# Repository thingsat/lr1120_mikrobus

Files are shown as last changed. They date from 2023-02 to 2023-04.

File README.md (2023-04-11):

# Semtech LR1120 Mikrobus Board

''The [LR1120](https://fr.semtech.com/products/wireless-rf/lora-edge/lr1120) is an ultra-low power device targeting global geolocation applications. It provides multi band LoRa® and Long Range - Frequency Hopping Spread Spectrum (LR-FHSS) communication over sub-GHz and 2.4GHz Industrial, Scientific and Medical (ISM) bands as well as licensed S-Band for satellites. It integrates a Cloud-native multi-constellation global navigation satellite system (GNSS) scanner and a passive Wi-Fi MAC address scanner, both leveraging [Semtech’s LoRa Cloud™ services](https://www.loracloud.com/documentation/modem_services?url=gls.html#apigeoloclr1110).''

The objective of this student homework is to adapt the [Semtech LR1120 `LR1120MB1DIS` eval board (868 MHz for the SubGhz interface)](https://fr.semtech.com/products/wireless-rf/lora-edge/lr1120dvk1tcks) to the convenient [Mikrobus form factor](https://download.mikroe.com/documents/standards/mikrobus/mikrobus-standard-specification-v200.pdf).

This project is being developed at [Polytech Grenoble](https://www.polytech-grenoble.fr/) and [CSUG](https://www.csug.fr/) ([Université Grenoble-Alpes](https://www.univ-grenoble-alpes.fr/)) by Dante Regiani Freitas and supervised by Prof. Didier Donsez.

## Hardware
* [Schematic](images/schematic.pdf)
* [Kicad design](./kicad)

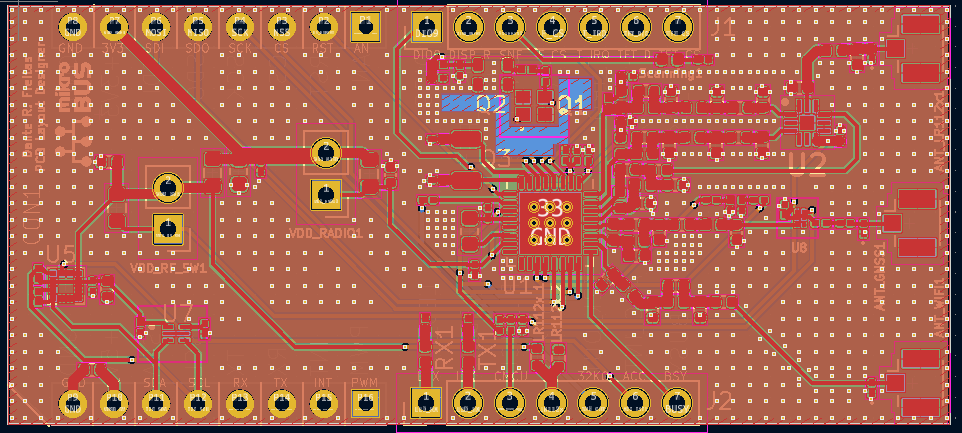
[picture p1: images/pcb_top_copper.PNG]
pcb_top_copper

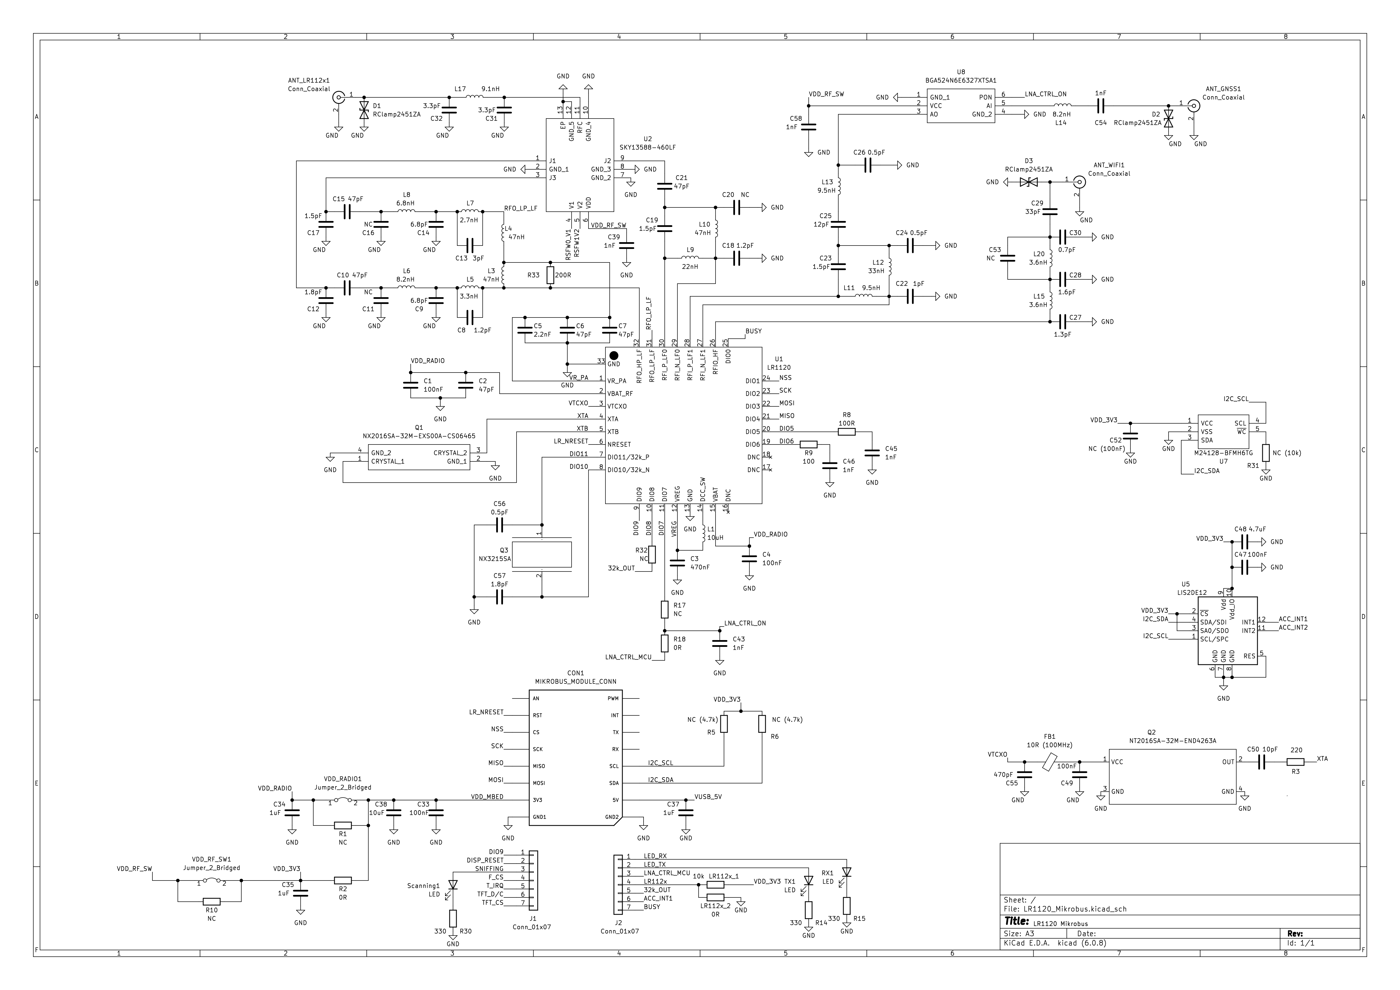
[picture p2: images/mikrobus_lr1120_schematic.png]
Mikrobus LR1120 schematic


## Firmware
* [Tutorial on LR11120](https://github.com/CampusIoT/tutorial/tree/master/lr1120)

## Misc
* [TinyGS 2.4 GHz Ground Station](https://github.com/thingsat/tinygs_2g4station)

## Media
LR1120MB1DIS

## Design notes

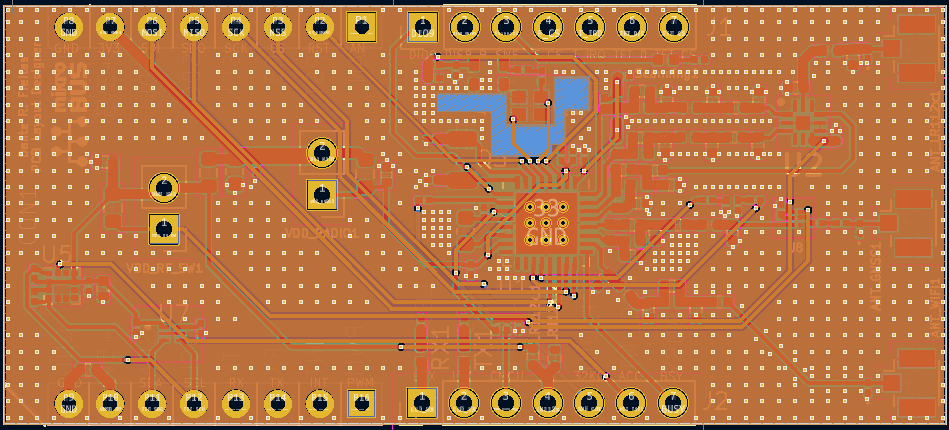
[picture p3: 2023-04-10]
images/pcb_inner_copper2.PNG

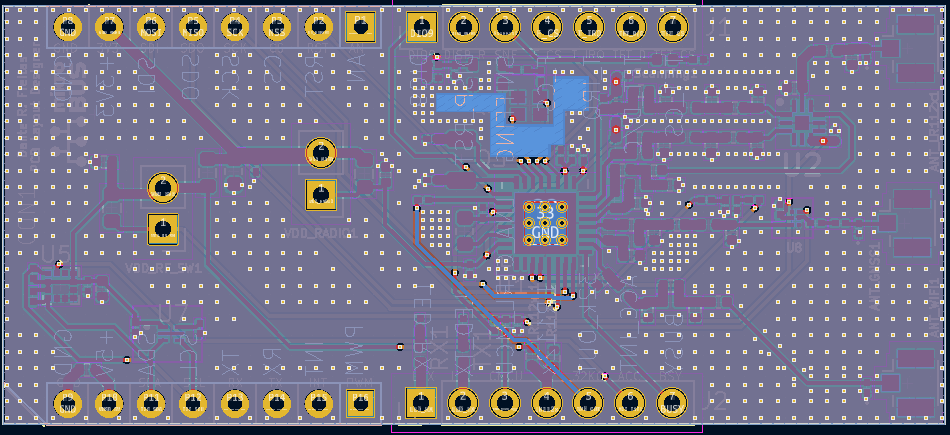
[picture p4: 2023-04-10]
images/pcb_bottom_copper.PNG

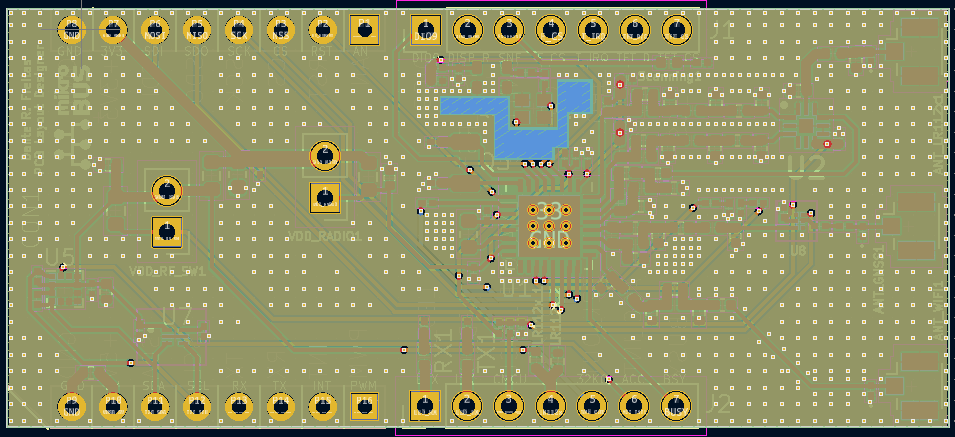
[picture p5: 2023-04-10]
images/pcb_inner_copper1.PNG

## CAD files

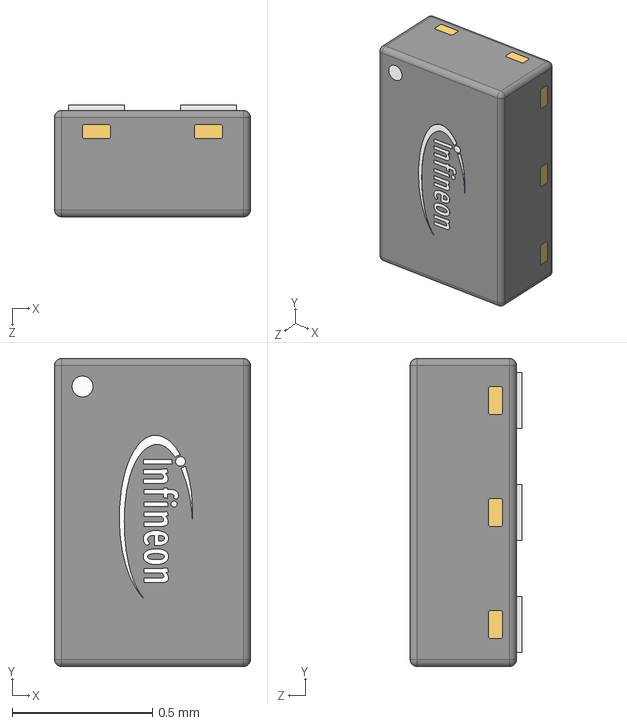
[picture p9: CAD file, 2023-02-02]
kicad/Impreintes/BGA524N6E6327XTSA1/3D/BGA524N6E6327XTSA1.stp
0.7 x 1.10 x 0.401 mm
BGA824N6E6327XTSA1
Infineon_Logo_1.4mm-LAPTOP-NQA1DCQ3

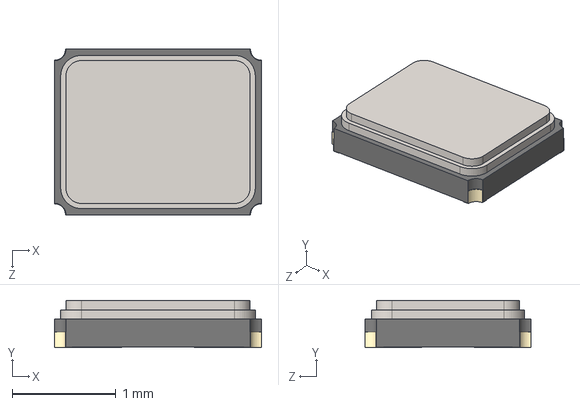
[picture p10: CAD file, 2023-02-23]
kicad/Impreintes/NX2016SA-32M-EXS00A-CS06465/3D/NX2016SA-32M-EXS00A-CS06465.stp
2.00 x 0.455 x 1.60 mm

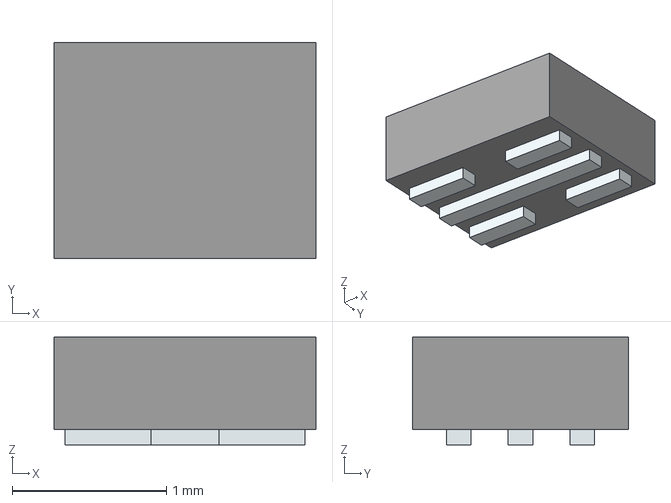
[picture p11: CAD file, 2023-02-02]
kicad/Impreintes/LIB_M24128-BFMH6TG/M24128-BFMH6TG/3D/M24128-BFMH6TG.stp
1.70 x 1.40 x 0.7 mm
Pins

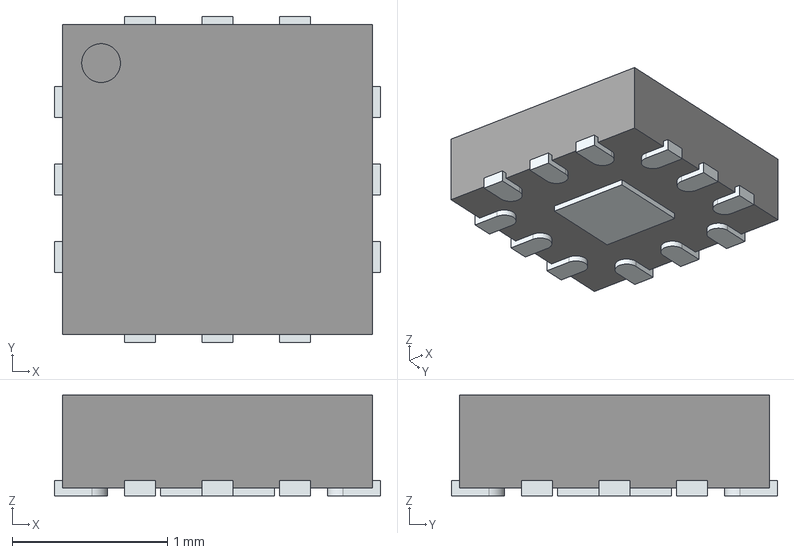
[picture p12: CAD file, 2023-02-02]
kicad/Impreintes/SKY13588-460LF/3D/SKY13588-460LF.stp
2.10 x 2.10 x 0.65 mm
ThermalPin
PinsArrayLR
PinsArrayTB

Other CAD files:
kicad/Impreintes/BGA524N6E6327XTSA1/Allegro/bgs12sn6e6327xtsa1.psm
kicad/Impreintes/BGA524N6E6327XTSA1/DEHDL/bga524n6e6327xtsa1/chips/chips.prt
kicad/Impreintes/LIB_M24128-BFMH6TG/M24128-BFMH6TG/Allegro/m24128bfmh6tg.psm
kicad/Impreintes/LIB_M24128-BFMH6TG/M24128-BFMH6TG/DEHDL/m24128_bfmh6tg/chips/chips.prt
kicad/Impreintes/NX2016SA-32M-EXS00A-CS06465/Allegro/nx2016sa32mexs00acs06465.psm
kicad/Impreintes/NX2016SA-32M-EXS00A-CS06465/DEHDL/nx2016sa_32m_exs00a_cs06465/chips/chips.prt
kicad/Impreintes/SKY13588-460LF/Allegro/qfn50p200x200x65-13n-d.psm
kicad/Impreintes/SKY13588-460LF/DEHDL/sky13588_460lf/chips/chips.prt

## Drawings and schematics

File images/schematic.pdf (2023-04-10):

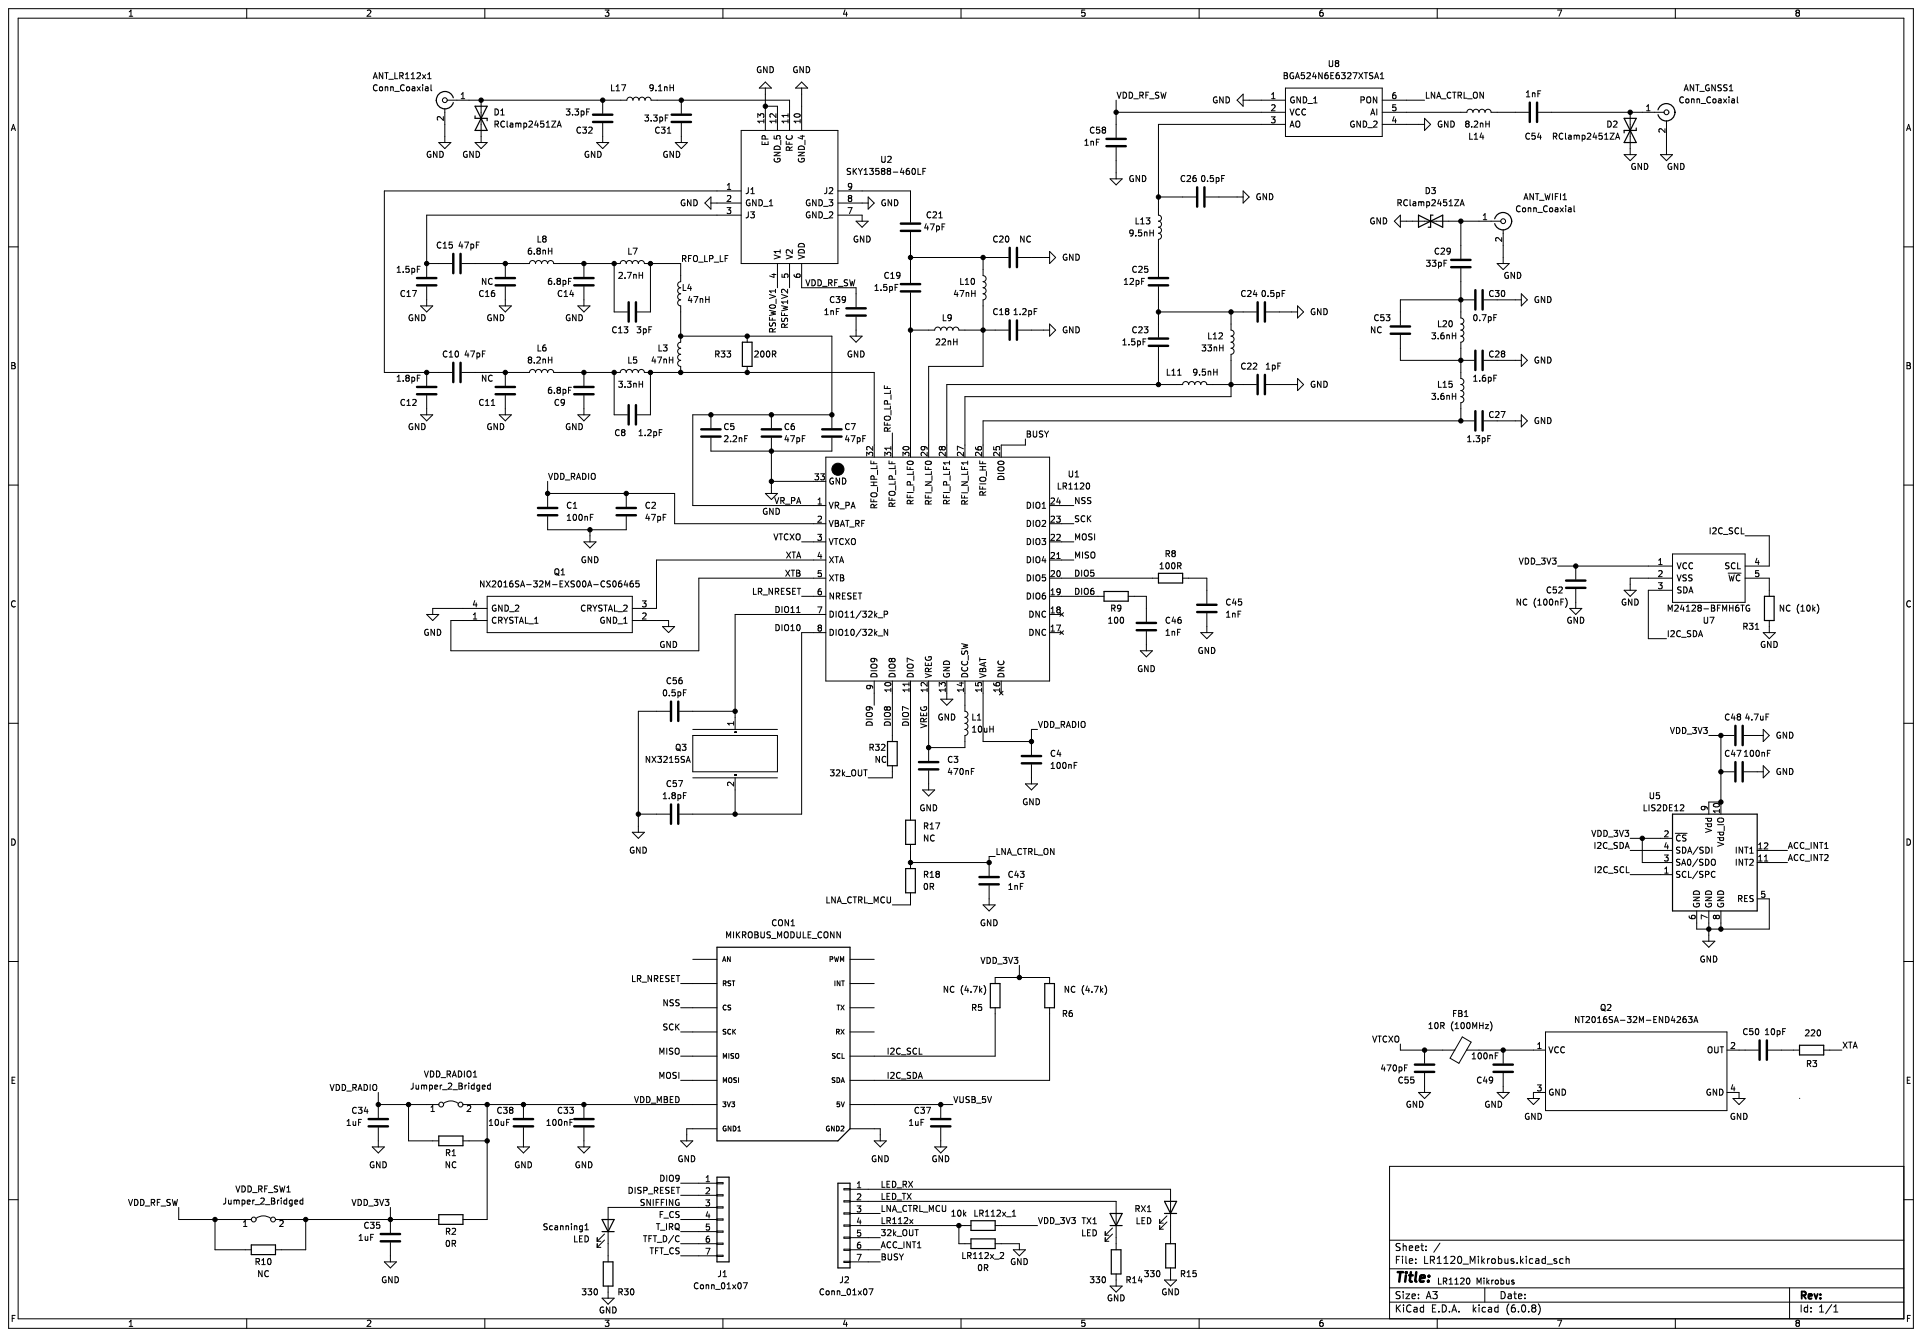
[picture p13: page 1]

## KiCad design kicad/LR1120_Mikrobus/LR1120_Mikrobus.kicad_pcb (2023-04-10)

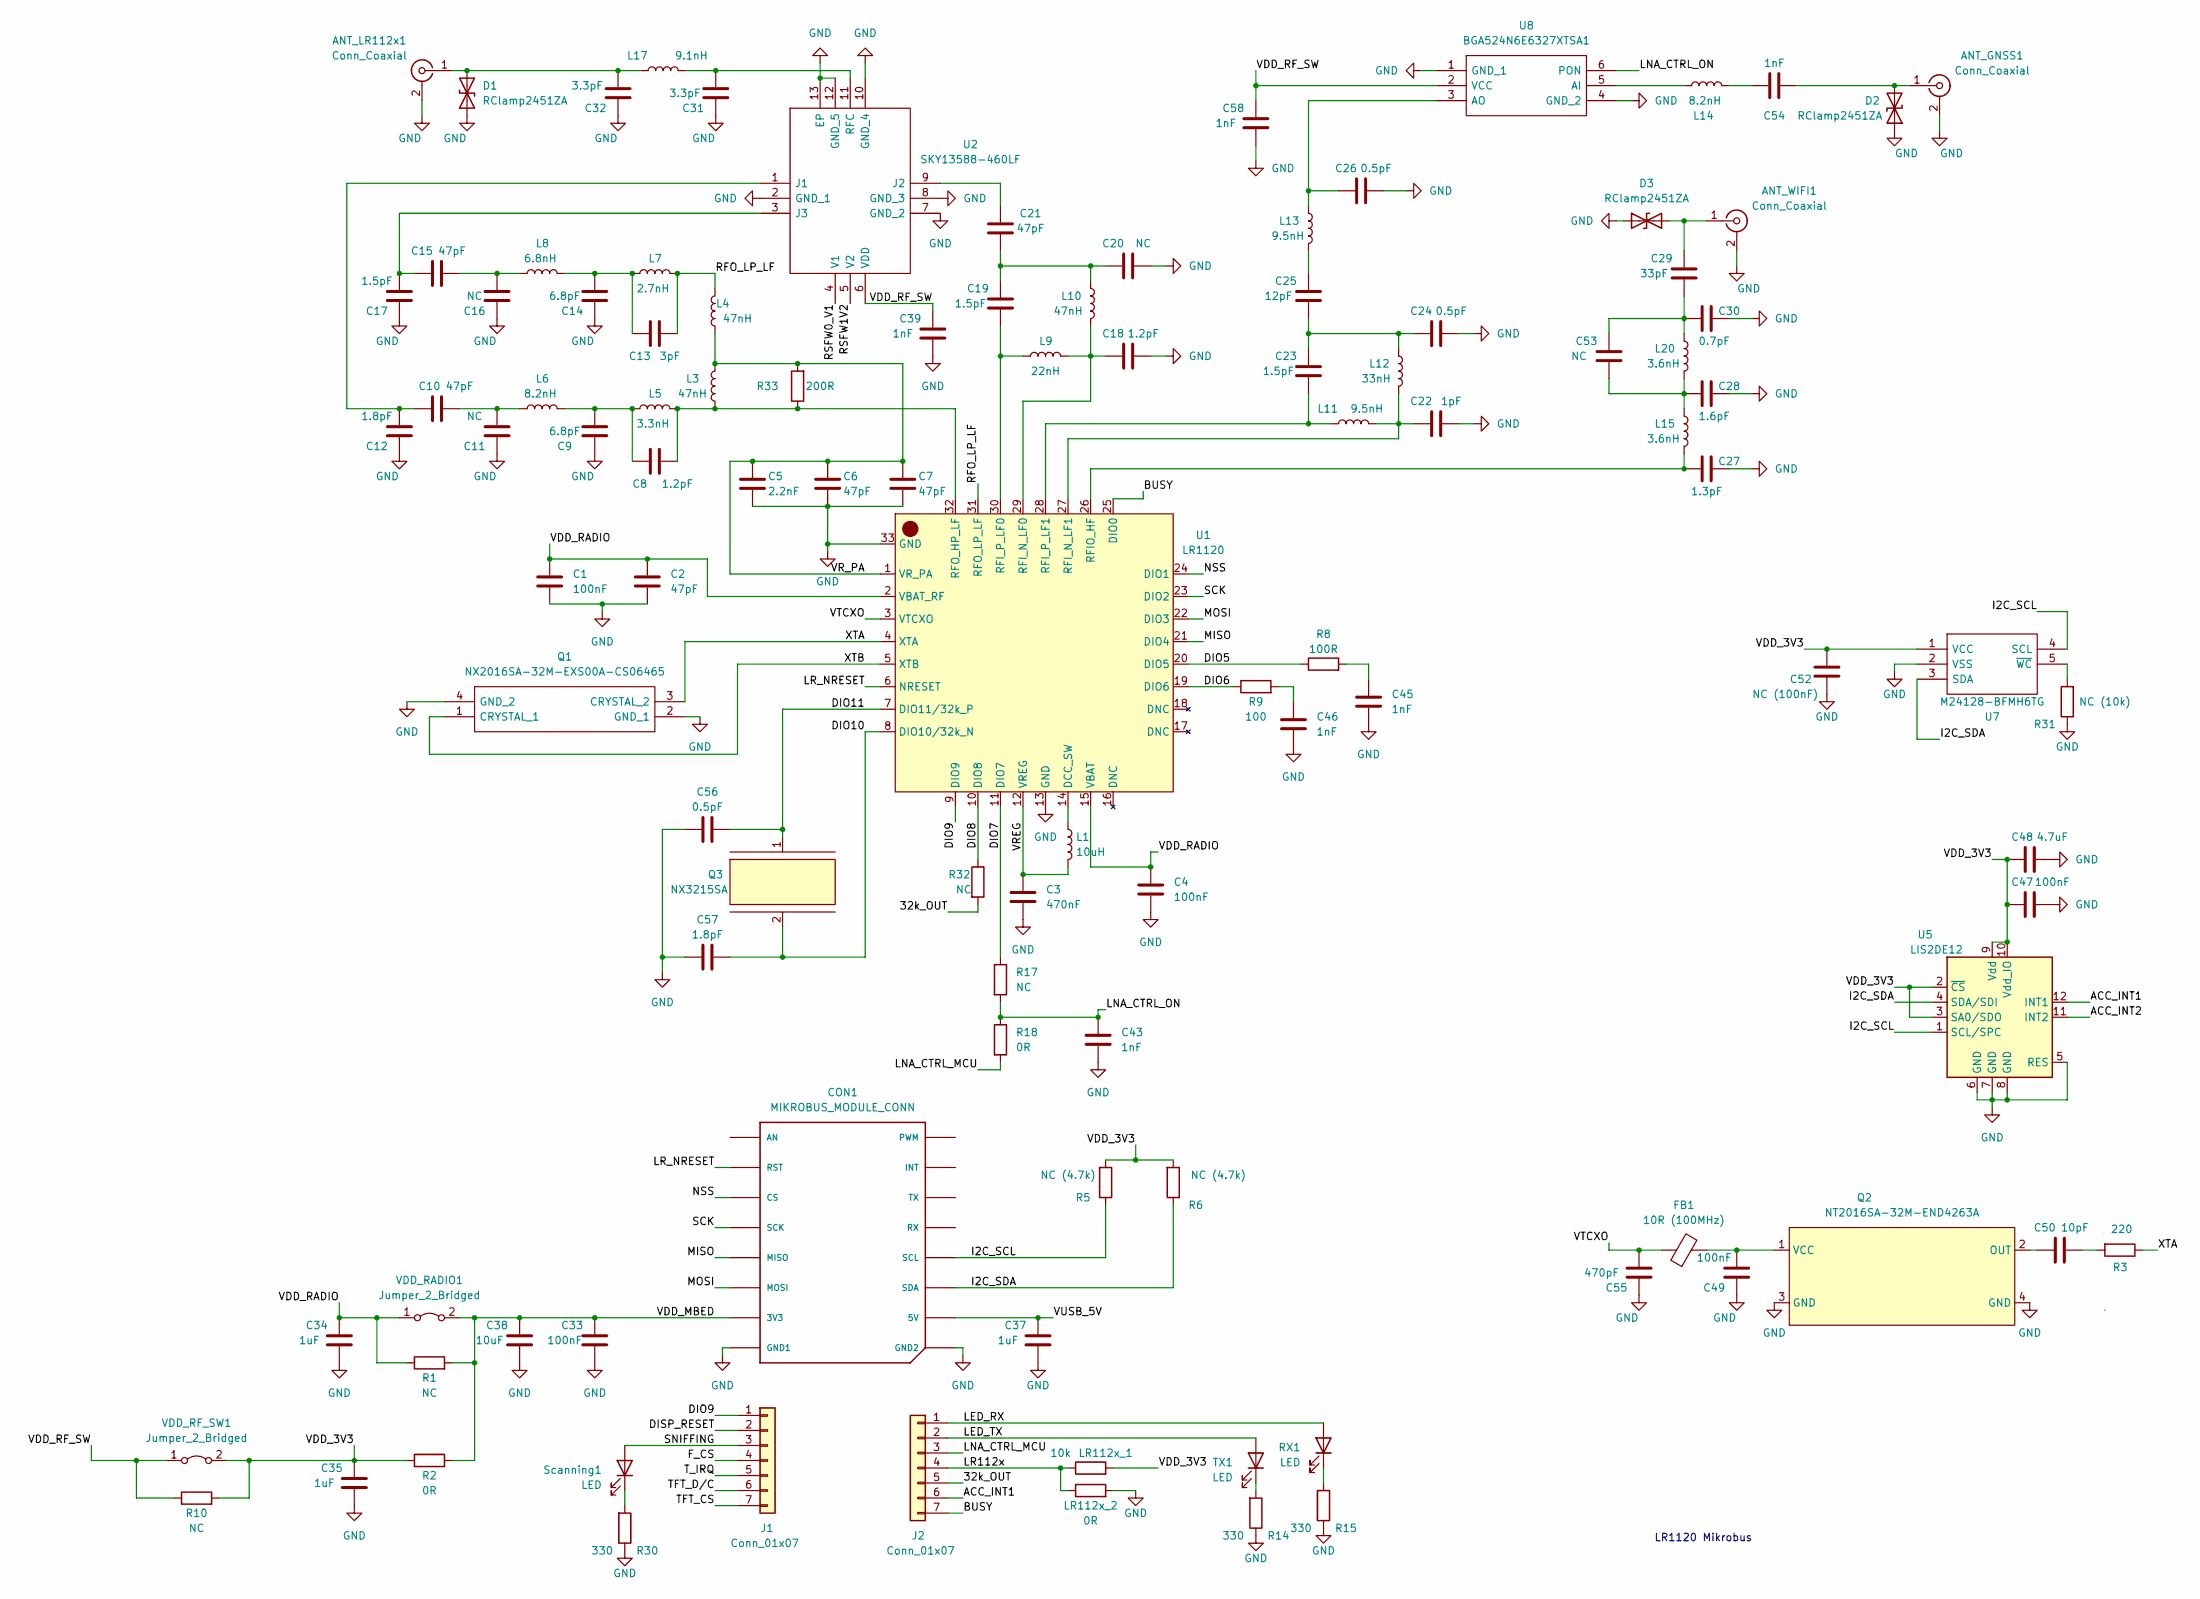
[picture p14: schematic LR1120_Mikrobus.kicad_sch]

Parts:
ANT_GNSS1: Conn_Coaxial; U.FL_Hirose_U.FL-R-SMT-1_Vertical
ANT_LR112x1: Conn_Coaxial; U.FL_Hirose_U.FL-R-SMT-1_Vertical
ANT_WIFI1: Conn_Coaxial; U.FL_Hirose_U.FL-R-SMT-1_Vertical
C1, C4, C33, C47, C49: 100nF; C_0201_0603Metric
C2, C6, C7: 47pF; C_0201_0603Metric
C3: 470nF; C_0201_0603Metric
C5: 2.2nF; C_0201_0603Metric
C8, C18: 1.2pF; C_0402_1005Metric
C9, C14: 6.8pF; C_0402_1005Metric
C10, C15, C21: 47pF; C_0402_1005Metric
C11, C16, C20, C53: NC; C_0402_1005Metric
C12: 1.8pF; C_0402_1005Metric
C13: 3pF; C_0402_1005Metric
C17, C19, C23: 1.5pF; C_0402_1005Metric
C22: 1pF; C_0402_1005Metric
C24, C26: 0.5pF; C_0402_1005Metric
C25: 12pF; C_0402_1005Metric
C27: 1.3pF; C_0402_1005Metric
C28: 1.6pF; C_0402_1005Metric
C29: 33pF; C_0402_1005Metric
C30: 0.7pF; C_0402_1005Metric
C31, C32: 3.3pF; C_0402_1005Metric
C34, C35, C37: 1uF; C_0402_1005Metric
C38: 10uF; C_0603_1608Metric
C39, C43, C45, C46, C54, C58: 1nF; C_0201_0603Metric
C48: 4.7uF; C_0402_1005Metric
C50: 10pF; C_0201_0603Metric
C52: NC (100nF); C_0201_0603Metric
C55: 470pF; C_0201_0603Metric
C56: 0.5pF; C_0201_0603Metric
C57: 1.8pF; C_0201_0603Metric
CON1: MIKROBUS_MODULE_CONN
D1, D2, D3: RClamp2451ZA; D_0201_0603Metric
FB1: 10R (100MHz); L_0201_0603Metric
J1, J2: Conn_01x07; PinHeader_1x07_P2.54mm_Vertical
L1: 10uH; L_0603_1608Metric
L3, L4, L10: 47nH; L_0402_1005Metric
L5: 3.3nH; L_0402_1005Metric
L6: 8.2nH; L_0402_1005Metric
L7: 2.7nH; L_0402_1005Metric
L8: 6.8nH; L_0402_1005Metric
L9: 22nH; L_0402_1005Metric
L11, L13: 9.5nH; L_0402_1005Metric
L12: 33nH; L_0402_1005Metric
L14: 8.2nH; L_0201_0603Metric
L15, L20: 3.6nH; L_0402_1005Metric
L17: 9.1nH; L_0402_1005Metric
LR112x_1: 10k; R_0402_1005Metric
LR112x_2: 0R; R_0402_1005Metric
Q1: NX2016SA-32M-EXS00A-CS06465; NX2016SA32MEXS00ACS06465; Mouser Part Number 344-NX2016SA32S06465
Q2: NT2016SA-32M-END4263A
Q3: NX3215SA
R1, R10: NC; R_0603_1608Metric
R2: 0R; R_0603_1608Metric
R3: 220; R_0201_0603Metric
R5, R6: NC (4.7k); R_0201_0603Metric
R8: 100R; R_0201_0603Metric
R9: 100; R_0201_0603Metric
R14, R15, R30: 330; R_0201_0603Metric
R17, R32: NC; R_0201_0603Metric
R18: 0R; R_0201_0603Metric
R31: NC (10k); R_0201_0603Metric
R33: 200R; R_0201_0603Metric
RX1: LED; LED_0402_1005Metric
Scanning1: LED; LED_0402_1005Metric
TX1: LED; LED_0402_1005Metric
U1: LR1120; QFN-32-1EP_5x5mm_P0.5mm_EP3.7x3.7mm_ThermalVias
U2: SKY13588-460LF; QFN50P200X200X65-13N-D; Mouser Part Number 873-SKY13588-460LF
U5: LIS2DE12; LGA-12_2x2mm_P0.5mm
U7: M24128-BFMH6TG; M24128BFMH6TG; Mouser Part Number 511-M24128-BFMH6TG
U8: BGA524N6E6327XTSA1; BGS12SN6E6327XTSA1; Mouser Part Number 726-A524N6E6327XTSA1
VDD_RADIO1: Jumper_2_Bridged; PinHeader_1x02_P2.54mm_Vertical
VDD_RF_SW1: Jumper_2_Bridged; PinHeader_1x02_P2.54mm_Vertical

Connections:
/32k_OUT: J2.5, R32.2
/ACC_INT1: J2.6, U5.12 (INT1)
/ACC_INT2: U5.11 (INT2)
/BUSY: J2.7, U1.25 (DIO0)
/DIO5: R8.1, U1.20 (DIO5)
/DIO6: R9.1, U1.19 (DIO6)
/DIO7: R17.1, U1.11 (DIO7)
/DIO8: R32.1, U1.10 (DIO8)
/DIO9: J1.1, U1.9 (DIO9)
/DIO10: C57.2, Q3.2 (C2), U1.8 (DIO10/32k_N)
/DIO11: C56.2, Q3.1 (C1), U1.7 (DIO11/32k_P)
/DISP_RESET: J1.2
/F_CS: J1.4
/I2C_SCL: CON1.P12 (SCL), R5.1, U5.1 (SCL/SPC), U7.4 (SCL)
/I2C_SDA: CON1.P11 (SDA), R6.1, U5.4 (SDA/SDI), U7.3 (SDA)
/LED_RX: J2.1, RX1.2 (A)
/LED_TX: J2.2, TX1.2 (A)
/LNA_CTRL_MCU: J2.3, R18.2
/LNA_CTRL_ON: C43.1, R17.2, R18.1, U8.6 (PON)
/LR112x: J2.4, LR112x_1.1, LR112x_2.1
/LR_NRESET: CON1.P2 (RST), U1.6 (NRESET)
/MISO: CON1.P5 (MISO), U1.21 (DIO4)
/MOSI: CON1.P6 (MOSI), U1.22 (DIO3)
/NSS: CON1.P3 (CS), U1.24 (DIO1)
/RFO_LP_LF: C13.1, L4.2, L7.2, U1.31 (RFO_LP_LF)
/RSFW0_V1: U2.4 (V1)
/RSFW1V2: U2.5 (V2)
/SCK: CON1.P4 (SCK), U1.23 (DIO2)
/SNIFFING: J1.3, Scanning1.2 (A)
/TFT_CS: J1.7
/TFT_D/C: J1.6
/T_IRQ: J1.5
/VDD_3V3: C35.2, C47.2, C48.2, C52.1, LR112x_1.2, R2.1, R5.2, R6.2, R10.2, U5.2 (~CS), U5.3 (SA0/SDO), U5.9 (Vdd), U5.10 (Vdd_IO), U7.1 (VCC), VDD_RF_SW1.2 (B)
/VDD_MBED: C33.2, C38.2, CON1.P7 (3V3), R1.2, R2.2, VDD_RADIO1.2 (B)
/VDD_RADIO: C1.1, C2.1, C4.1, C34.2, R1.1, U1.2 (VBAT_RF), U1.15 (VBAT), VDD_RADIO1.1 (A)
/VDD_RF_SW: C39.2, C58.2, R10.1, U2.6 (VDD), U8.2 (VCC), VDD_RF_SW1.1 (A)
/VREG: C3.1, L1.2, U1.12 (VREG)
/VR_PA: C5.1, C6.1, C7.1, L3.2, L4.1, R33.2, U1.1 (VR_PA)
/VTCXO: C55.1, FB1.1, U1.3 (VTCXO)
/VUSB_5V: C37.2, CON1.P10 (5V)
/XTA: Q1.3 (CRYSTAL_2), R3.1, U1.4 (XTA)
/XTB: Q1.1 (CRYSTAL_1), U1.5 (XTB)
GND: ANT_GNSS1.2 (Ext), ANT_LR112x1.2 (Ext), ANT_WIFI1.2 (Ext), C1.2, C2.2, C3.2, C4.2, C5.2, C6.2, C7.2, C9.2, C11.2, C12.2, C14.2, C16.2, C17.2, C18.1, C20.1, C22.1, C24.1, C26.1, C27.2, C28.2, C30.2, C31.2, C32.2, C33.1, C34.1, C35.1, C37.1, C38.1, C39.1, C43.2, C45.2, C46.2, C47.1, C48.1, C49.2, C52.2, C55.2, C56.1, C57.1, C58.1, CON1.P8 (GND1), CON1.P9 (GND2), D1.1 (A1), D2.1 (A1), D3.1 (A1), LR112x_2.2, Q1.2 (GND_1), Q1.4 (GND_2), Q2.3 (GND), Q2.4 (GND), R14.1, R15.1, R30.1, R31.1, U1.13 (GND), U1.33 (GND), U2.2 (GND_1), U2.7 (GND_2), U2.8 (GND_3), U2.10 (GND_4), U2.12 (GND_5), U2.13 (EP), U5.5 (RES), U5.6 (GND), U5.7 (GND), U5.8 (GND), U7.2 (VSS), U8.1 (GND_1), U8.4 (GND_2)
unnamed: ANT_GNSS1.1 (In), C54.1, D2.2 (A2)
unnamed: ANT_LR112x1.1 (In), C32.1, D1.2 (A2), L17.1
unnamed: ANT_WIFI1.1 (In), C29.2, D3.2 (A2)
unnamed: C8.1, L3.1, L5.2, R33.1, U1.32 (RFO_HP_LF)
unnamed: C8.2, C9.1, L5.1, L6.2
unnamed: C10.1, C11.1, L6.1
unnamed: C10.2, C12.1, U2.1 (J1)
unnamed: C13.2, C14.1, L7.1, L8.2
unnamed: C15.1, C16.1, L8.1
unnamed: C15.2, C17.1, U2.3 (J3)
unnamed: C18.2, L9.2, L10.2, U1.29 (RFI_N_LF0)
unnamed: C19.1, L9.1, U1.30 (RFI_P_LF0)
unnamed: C19.2, C20.2, C21.1, L10.1
unnamed: C21.2, U2.9 (J2)
unnamed: C22.2, L11.2, L12.2, U1.27 (RFI_N_LF1)
unnamed: C23.1, L11.1, U1.28 (RFI_P_LF1)
unnamed: C23.2, C24.2, C25.1, L12.1
unnamed: C25.2, L13.2
unnamed: C26.2, L13.1, U8.3 (AO)
unnamed: C27.1, L15.2, U1.26 (RFIO_HF)
unnamed: C28.1, C53.1, L15.1, L20.2
unnamed: C29.1, C30.1, C53.2, L20.1
unnamed: C31.1, L17.2, U2.11 (RFC)
unnamed: C45.1, R8.2
unnamed: C46.1, R9.2
unnamed: C49.1, FB1.2, Q2.1 (VCC)
unnamed: C50.1, R3.2
unnamed: C50.2, Q2.2 (OUT)
unnamed: C54.2, L14.2
unnamed: L1.1, U1.14 (DCC_SW)
unnamed: L14.1, U8.5 (AI)
unnamed: R14.2, TX1.1 (K)
unnamed: R15.2, RX1.1 (K)
unnamed: R30.2, Scanning1.1 (K)
unnamed: R31.2, U7.5 (~WC)

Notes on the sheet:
LR1120 Mikrobus

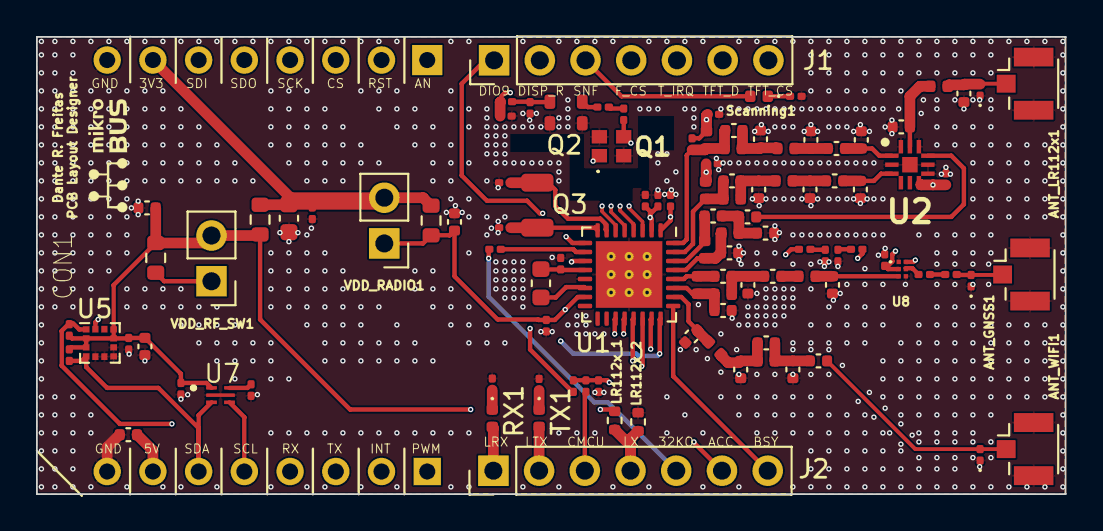
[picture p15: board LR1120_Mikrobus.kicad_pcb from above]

Board: 4 copper layers, 57.2 x 25.4 mm, 109 parts (0 on the bottom side), 70 nets.

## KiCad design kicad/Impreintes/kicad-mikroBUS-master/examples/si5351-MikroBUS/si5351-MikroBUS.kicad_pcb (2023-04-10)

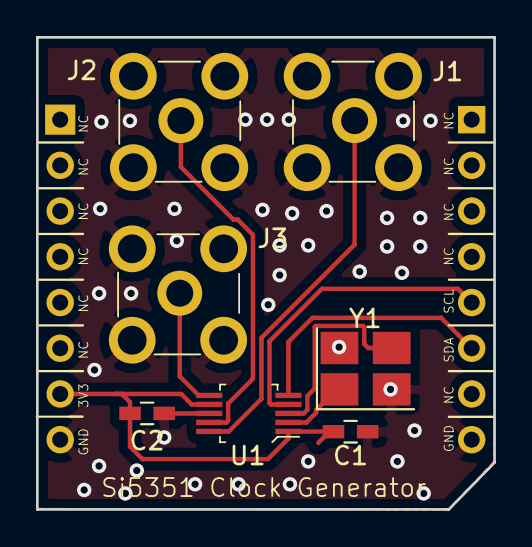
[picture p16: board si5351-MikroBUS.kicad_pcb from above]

Board: 2 copper layers, 25.4 x 26.2 mm, 9 parts (1 on the bottom side), 9 nets.

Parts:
*: MIKROCLICK_LOGO; MIKROBUS_LOGO
C1, C2: 0.1u; C_0603_HandSoldering
CON101: MIKROBUS_MODULE_CONN
J1, J2, J3: 5-1814832-1; RF_SMA_Vertical_5-1814832-1
U1: SI5351A-B-GT; MSOP-10_W3mm
Y1: 27 MHz; Crystal_SMD_3225-4pin_3.2x2.5mm_HandSoldering

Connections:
+3V3: C1.1, C2.2, CON101.P7, U1.1, U1.7
/SCL: CON101.P12, U1.4
/SDA: CON101.P11, U1.5
GND: C1.2, C2.1, CON101.P8, CON101.P9, J1.1, J2.1, J3.1, U1.8, Y1.2, Y1.4
unnamed: J1.2, U1.10
unnamed: J2.2, U1.9
unnamed: J3.2, U1.6
unnamed: U1.2, Y1.1
unnamed: U1.3, Y1.3

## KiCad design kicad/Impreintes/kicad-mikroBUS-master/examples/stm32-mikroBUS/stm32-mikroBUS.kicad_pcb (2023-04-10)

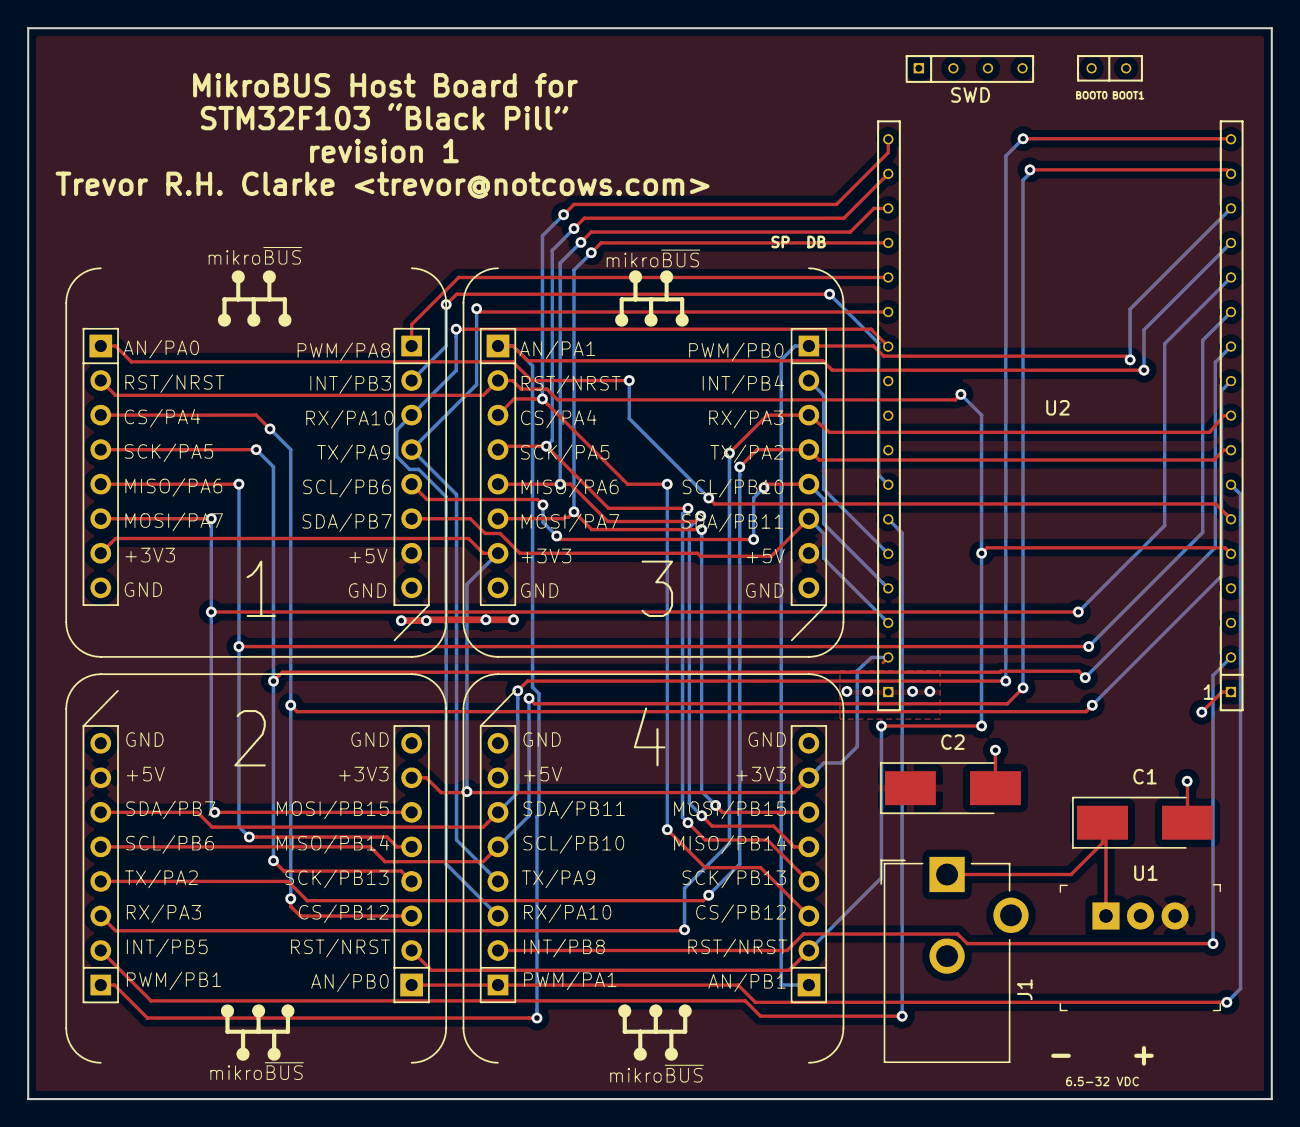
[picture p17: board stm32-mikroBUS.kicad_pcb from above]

Board: 2 copper layers, 91.4 x 78.7 mm, 9 parts (0 on the bottom side), 30 nets.

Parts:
C1: 10u/50V; CP_Tantalum_Case-C_EIA-6032-28_Hand
C2: 22u/16V; CP_Tantalum_Case-C_EIA-6032-28_Hand
CON1: 1; MIKROBUS_HOST_CONN
CON2: 2; MIKROBUS_HOST_CONN
CON3: 3; MIKROBUS_HOST_CONN
CON4: 4; MIKROBUS_HOST_CONN
J1: 6.5-32 VDC; Barrel_Jack_CUI_PJ-102AH
U1: V7805-1000; 3-SIP_Module_V7805-1000
U2: BlackPill

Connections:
+3V3: CON1.P7, CON2.P7, CON3.P7, CON4.P7, U2.33
+5V: C2.1, CON1.P10, CON2.P10, CON3.P10, CON4.P10, U1.3
/A1: CON1.P1, U2.6
/A2: CON2.P1, CON4.P16, U2.7
/A3: CON2.P16, CON3.P1, U2.14
/A4: CON3.P16, CON4.P1, U2.15
/I1: CON1.P15, U2.28
/I2: CON2.P15, U2.29
/I3: CON3.P15, U2.30
/I4: CON4.P15, U2.2
/MISO1: CON1.P5, CON2.P5, U2.12
/MISO2: CON3.P5, CON4.P5, U2.20
/MOSI1: CON1.P6, CON2.P6, U2.13
/MOSI2: CON3.P6, CON4.P6, U2.21
/PWM1: CON1.P16, U2.22
/RX1: CON1.P14, CON4.P14, U2.24
/RX2: CON2.P14, CON3.P14, U2.9
/SCK1: CON1.P4, CON2.P4, U2.11
/SCK2: CON3.P4, CON4.P4, U2.19
/SCL1: CON1.P12, CON3.P12, U2.31
/SCL2: CON2.P12, CON4.P12, U2.16
/SDA1: CON1.P11, CON3.P11, U2.32
/SDA2: CON2.P11, CON4.P11, U2.17
/SS1: CON1.P3, CON2.P3, U2.10
/SS2: CON3.P3, CON4.P3, U2.18
/TX1: CON1.P13, CON4.P13, U2.23
/TX2: CON2.P13, CON3.P13, U2.8
GND: C1.2, C2.2, CON1.P8, CON1.P9, CON2.P8, CON2.P9, CON3.P8, CON3.P9, CON4.P8, CON4.P9, J1.2, U1.2, U2.1, U2.34
unnamed: C1.1, J1.1, U1.1
unnamed: CON1.P2, CON2.P2, CON3.P2, CON4.P2, U2.5

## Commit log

2023-02-02 add dirs for kicad and firmware
2023-02-02 add kicad project and footprints
    [BGA524N6E6327XTSA1.SchLib, BGA524N6E6327XTSA1.stp, BGS12SN6E6327XTSA1.PcbLib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]
2023-02-09 TCXO doc et composant Kicad
    Téléchargement de la documentation du TCXO et création de se composant sur Kicad
2023-02-09 Small corrections from last commit
    [LR1120_Mikrobus.kicad_sch]
2023-02-23 tcxo footprint and symbol ready
    [LR1120_Mikrobus.kicad_sch]
2023-02-23 Q2 and Q3 placed
    downloaded Q2 symbol and footprint. created Q3 symbol and footprint
    [EDI2CAP.CFG, LR1120_Mikrobus.kicad_sch, NX2016SA-32M-EXS00A-CS06465.SchLib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]
2023-03-02 added some res, ind and caps
    added R9, R10, R17, R18 and R32. added C1-C7, C43-C46, C56 and C57. added L1.
    [LR1120_Mikrobus.kicad_sch]
2023-03-09 added caps, inds and rclamp
    Added C22-C26, C27-C28, C30, C53 and C58
    Added L11-L13, L15 and L20
    Added D3 (rclamp)
    [LR1120_Mikrobus.kicad_sch]
2023-03-16 Added caps, inds and res
    Adeded remaining caps, inds and res, but C47-48, C52 and R31. Some caps, inds and res need be set to the correct footprint and value.
    [LR1120_Mikrobus.kicad_sch]
2023-03-26 Added all comp, except connectors
    Added almost all components. Still remains to be placed the microbus connector and the associated caps, res and switches
    [LR1120_Mikrobus.kicad_sch]
2023-03-27 Here we are changing the value of the capacitors that has conflicts in the table, in the schematics they have 0.5 pF value, but in table is NC
2023-03-27 New changes
    [LR1120_Mikrobus.kicad_sch]
2023-03-27 Changes: C14 "0.5pF -> 6.8pF
    [LR1120_Mikrobus.kicad_sch]
2023-03-27 Resistor R3 modified to 220 ohms, previously not marked in the BOM table.
    TX and RX LED done
    I2C and SPI communication link between LR1120 and Mikrobus done
    3.3 V link done
    [LR1120_Mikrobus.kicad_sch]
2023-03-27 All original pins of mikrobus paired. Led's done
    [LR1120_Mikrobus.kicad_sch]
2023-03-27 Commit save dante
    [LR1120_Mikrobus.kicad_sch]
2023-03-30 created board edges, added ant
    Created board edges, placed antennas
    [LR1120_Mikrobus.kicad_pcb, LR1120_Mikrobus.kicad_sch]
2023-03-31 all components placed
    all components have been placed. some footprints remain to be properly setup
    [LR1120_Mikrobus.kicad_sch]
2023-04-02 all footprints assigned
    All footprints were properly assingned according to the original BOM.
    [LR1120_Mikrobus.kicad_sch]
2023-04-03 PCB:populated comp placed connectors
    Populated the PCB with all the components. Placed and locked the connectors
    [LR1120_Mikrobus.kicad_pcb, LR1120_Mikrobus.kicad_sch, mikroBUS-L.kicad_pcb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]
2023-04-03 other components placed
    placed: U2, U8, U1. Q1, Q2 Q3.
    [LR1120_Mikrobus.kicad_pcb]
2023-04-05 more components placed
    [LR1120_Mikrobus.kicad_pcb, LR1120_Mikrobus.kicad_sch]
2023-04-05 All components placed
    Last step: routing
    [LR1120_Mikrobus.kicad_sch]
2023-04-05 all routes traced. ground planes set.
    All routes were traced, The ground planes were set with the appropriate cut out for the crystal oscillators.
    [LR1120_Mikrobus.kicad_sch]
2023-04-05 stitched vias. inserted uBUS logo.
2023-04-06 add dir for gerber files
2023-04-10 pcb design guideline checked
    [LR1120_Mikrobus.kicad_pcb, LR1120_Mikrobus.kicad_sch]
2023-04-10 gerbers generated
    [LR1120_Mikrobus-B_Cu.gbr, LR1120_Mikrobus-B_Mask.gbr, LR1120_Mikrobus-B_Paste.gbr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]
2023-04-11 remove lores schematic
2023-04-11 add hires schematic
